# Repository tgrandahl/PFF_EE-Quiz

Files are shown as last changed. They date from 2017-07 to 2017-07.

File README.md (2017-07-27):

# PFF_EE-Quiz
EE-Quiz for PFF screening
Tyler Grandahl - July 27th 2017

The design files are provided in response to the following request:

Using KiCAD, design a circuit schematic for an analog amplifier with the following features:
-Uses a 5VDC power supply. Assumes the signal to be amplified shares the same ground as the power supply.
-Amplifies an input analog signal that can range from 0 to 2.0V so that the output ranges from 0 to 5V.
-Contains a bill of materials (BOM) specifying the chosen components and how to source them.
-Has an adjustable gain. And a low-pass filter with adjustable cut-off to filter-out noise from the input analog signal.
-OPTIONAL: Is implemented as a routed PCB.
 
The design can be submitted as a GitHub repository file containing the KiCAD project and a printable (Letter) PDF with the schematic and if available another PDF in 1:1 scale of the routed PCB.

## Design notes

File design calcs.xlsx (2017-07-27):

Amplifier Gain
rf min | 1000
rf max | 100000
ri | 10000
g min | 1.1
g max | 11
Max BW @ Max Gain
GBP | 5500000
BW @ max gain | 500000 | <= will keep max cutoff of input filter below this
Input Filter cutoff
Rin min | 1000
Rin max | 100000
Cin | 4.7e-09
fc max | 33862.75385
fc min | 338.6275385

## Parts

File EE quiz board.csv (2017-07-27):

Reference | Value | Footprint | Datasheet | MFG | MFG PN | Description
J3 | Screw_Terminal_1x02 | Connectors_Terminal_Blocks:TerminalBlock_Pheonix_MKDS1.5-2pol | https://media.digikey.com/PDF/Data%20Sheets/Phoenix%20Contact%20PDFs/1868733.pdf | Phoenix Contact | 1868733 | CONN TERM BLOCK 2POS 5.08
RV1 | 100k | Potentiometers:Potentiometer_Bourns_PTV09A-1_Horizontal | http://www.bourns.com/docs/Product-Datasheets/PTV09.pdf | Bourns | PTV09A-4025F-B104 | POT 100K OHM 1/20W CARBON LINEAR
R2 | 10k | Resistors_SMD:R_0603_HandSoldering | https://industrial.panasonic.com/cdbs/www-data/pdf/RDO0000/AOA0000C331.pdf | Panasonic Electronic Components | ERJ-PA3F1002V | RES SMD 10K OHM 1% 1/4W 0603
C3 | 0.1uF | Capacitors_SMD:C_0603_HandSoldering | http://www.kemet.com/Lists/ProductCatalog/Attachments/53/KEM_C1002_X7R_SMD.pdf | KEMET | C0603C104K4RACTU | CAP CER 0.1UF 16V X7R 0603
C2 | 4.7nF | Capacitors_SMD:C_0603_HandSoldering | http://www.kemet.com/Lists/ProductCatalog/Attachments/53/KEM_C1002_X7R_SMD.pdf | KEMET | C0603C472K4RACTU | CAP CER 4700PF 16V X7R 0603
C1 | 10uF | Capacitors_Tantalum_SMD:CP_Tantalum_Case-A_EIA-3216-18_Hand | http://www.kemet.com/Lists/ProductCatalog/Attachments/256/KEM_T2008_T494.pdf | KEMET | T494A106K016AT | CAP TANT 10UF 16V 10% 1206
U1 | OPA340D | Housings_SOIC:SOIC-8_3.9x4.9mm_Pitch1.27mm | http://www.ti.com/lit/ds/symlink/opa2340.pdf | TI | OPA340UA/2K5 | IC OP AMP GP 5.5MHZ RRIO 8SOIC
RV2 | 100k | Potentiometers:Potentiometer_Bourns_PTV09A-1_Horizontal | http://www.bourns.com/docs/Product-Datasheets/PTV09.pdf | Bourns | PTV09A-4025F-B104 | POT 100K OHM 1/20W CARBON LINEAR
J2 | Screw_Terminal_1x02 | Connectors_Terminal_Blocks:TerminalBlock_Pheonix_MKDS1.5-2pol | https://media.digikey.com/PDF/Data%20Sheets/Phoenix%20Contact%20PDFs/1868733.pdf | Phoenix Contact | 1868733 | CONN TERM BLOCK 2POS 5.08
J1 | Screw_Terminal_1x02 | Connectors_Terminal_Blocks:TerminalBlock_Pheonix_MKDS1.5-2pol | https://media.digikey.com/PDF/Data%20Sheets/Phoenix%20Contact%20PDFs/1868733.pdf | Phoenix Contact | 1868733 | CONN TERM BLOCK 2POS 5.08
D2 | D_Schottky_x2_Serial_AKC | TO_SOT_Packages_SMD:SOT-23_Handsoldering | http://www.onsemi.com/pub/Collateral/BAT54SLT1-D.PDF | ON Semiconductor | SBAT54SLT1G | DIODE ARRAY SCHOTTKY 30V SOT23-3
D1 | LED | LEDs:LED_0805_HandSoldering | https://media.digikey.com/pdf/Data%20Sheets/Lite-On%20PDFs/LTST-C171GKT.pdf | Lite-On | LTST-C171GKT | LED GREEN CLEAR 0805 SMD
R1 | 147 | Resistors_SMD:R_0603_HandSoldering | https://industrial.panasonic.com/cdbs/www-data/pdf/RDO0000/AOA0000C331.pdf | Panasonic Electronic Components | ERJ-3EKF1470V | RES SMD 147 OHM 1% 1/4W 0603

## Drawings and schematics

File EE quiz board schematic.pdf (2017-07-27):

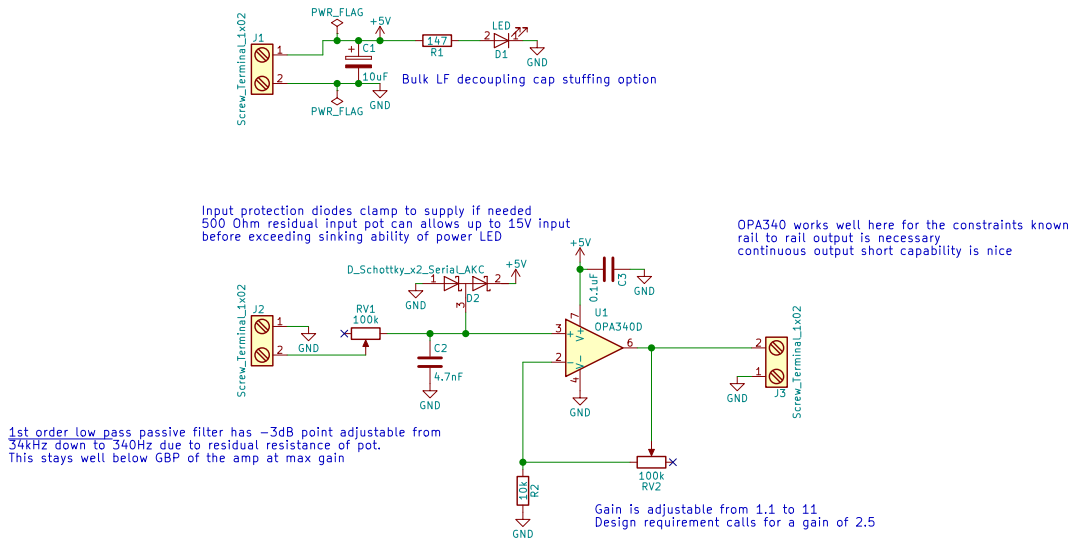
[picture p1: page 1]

Input protection diodes clamp to supply if needed
500 Ohm residual input pot can allows up to 15V input
before exceeding sinking ability of power LED

OPA340 works well here for the constraints known
rail to rail output is necessary
continuous output short capability is nice

1st order low pass passive filter has -3dB point adjustable from
34kHz down to 340Hz due to residual resistance of pot.
This stays well below GBP of the amp at max gain

Design requirement calls for a gain of 2.5 RV2
Gain is adjustable from 1.1 to 11

File: EE quiz board.sch Sheet: / Piaggio Fast Forward

Id: 1/1 Title: EE quiz board

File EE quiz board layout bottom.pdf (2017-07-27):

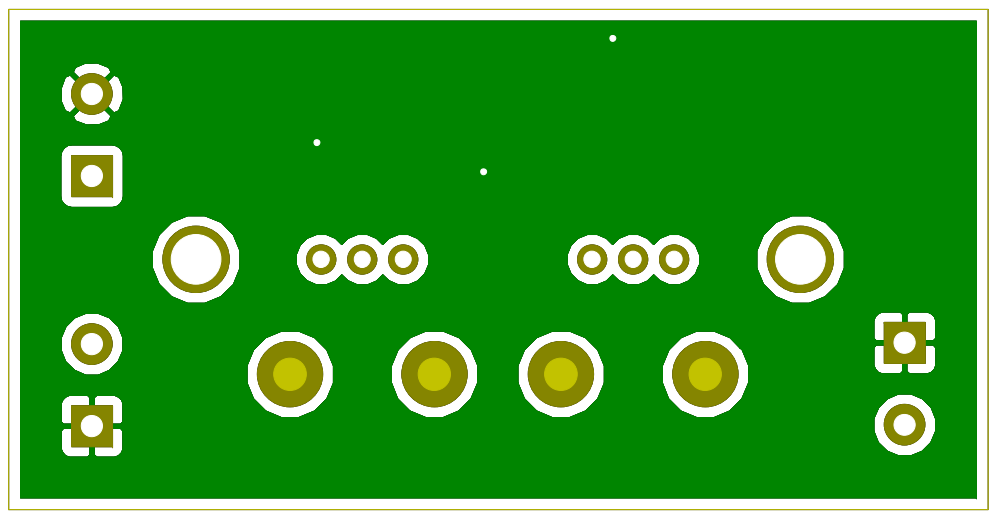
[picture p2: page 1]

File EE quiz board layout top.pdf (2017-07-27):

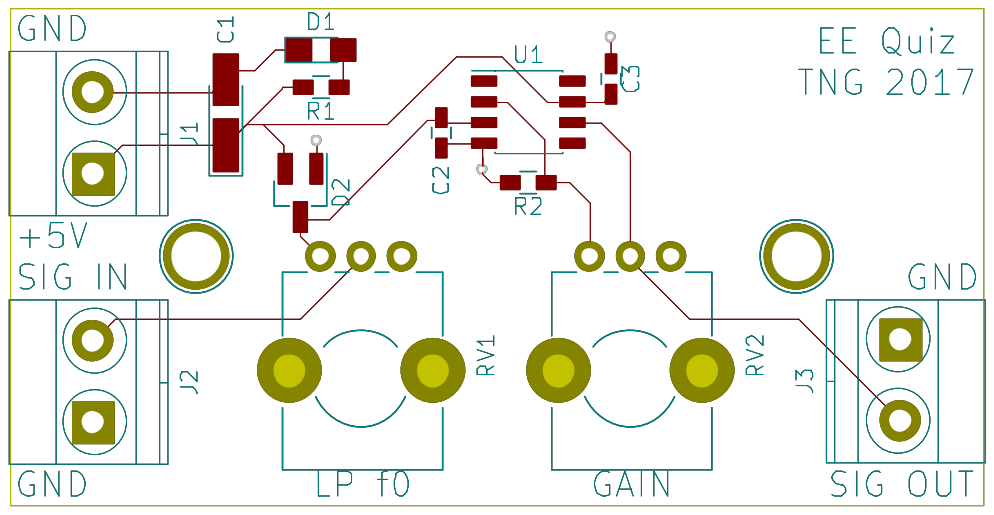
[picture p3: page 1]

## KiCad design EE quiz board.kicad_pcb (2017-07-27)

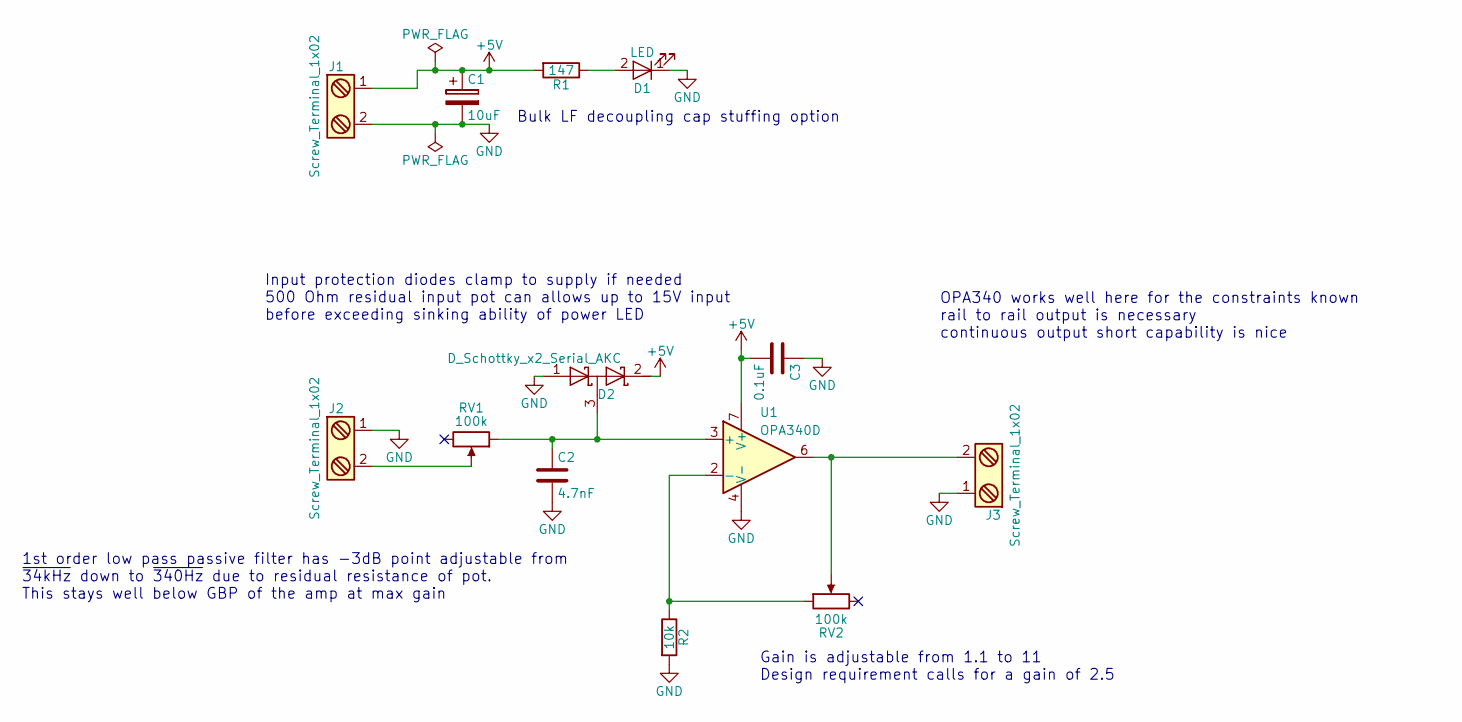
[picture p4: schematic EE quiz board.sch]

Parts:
C1: 10uF; CP_Tantalum_Case-A_EIA-3216-18_Hand; MFG PN T494A106K016AT
C2: 4.7nF; C_0603_HandSoldering; MFG PN C0603C472K4RACTU
C3: 0.1uF; C_0603_HandSoldering; MFG PN C0603C104K4RACTU
D1: LED; LED_0805_HandSoldering; MFG PN LTST-C171GKT
D2: D_Schottky_x2_Serial_AKC; SOT-23_Handsoldering; MFG PN SBAT54SLT1G
J1, J2, J3: Screw_Terminal_1x02; TerminalBlock_Pheonix_MKDS1.5-2pol; MFG PN 1868733
R1: 147; R_0603_HandSoldering; MFG PN ERJ-3EKF1470V
R2: 10k; R_0603_HandSoldering; MFG PN ERJ-PA3F1002V
RV1, RV2: 100k; Potentiometer_Bourns_PTV09A-1_Horizontal; MFG PN PTV09A-4025F-B104
U1: OPA340D; SOIC-8_3.9x4.9mm_Pitch1.27mm; MFG PN OPA340UA/2K5

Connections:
+5V: C1.1, C3.2, D2.2 (K), J1.1, R1.2, U1.7 (V+)
GND: C1.2, C2.2, C3.1, D1.1 (K), D2.1 (A), J1.2, J2.1, J3.1, R2.2, U1.4 (V-)
unnamed: C2.1, D2.3 (common), RV1.1, U1.3 (+)
unnamed: D1.2 (A), R1.1
unnamed: J2.2, RV1.2
unnamed: J3.2, RV2.2, U1.6
unnamed: R2.1, RV2.1, U1.2 (-)

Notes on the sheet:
Input protection diodes clamp to supply if needed 500 Ohm residual input pot can allows up to 15V input before exceeding sinking ability of power LED
OPA340 works well here for the constraints known rail to rail output is necessary continuous output short capability is nice
1st order low pass passive filter has -3dB point adjustable from ~34kHz down to ~340Hz due to residual resistance of pot. This stays well below GBP of the amp at max gain
Gain is adjustable from 1.1 to 11 Design requirement calls for a gain of 2.5
Bulk LF decoupling cap stuffing option

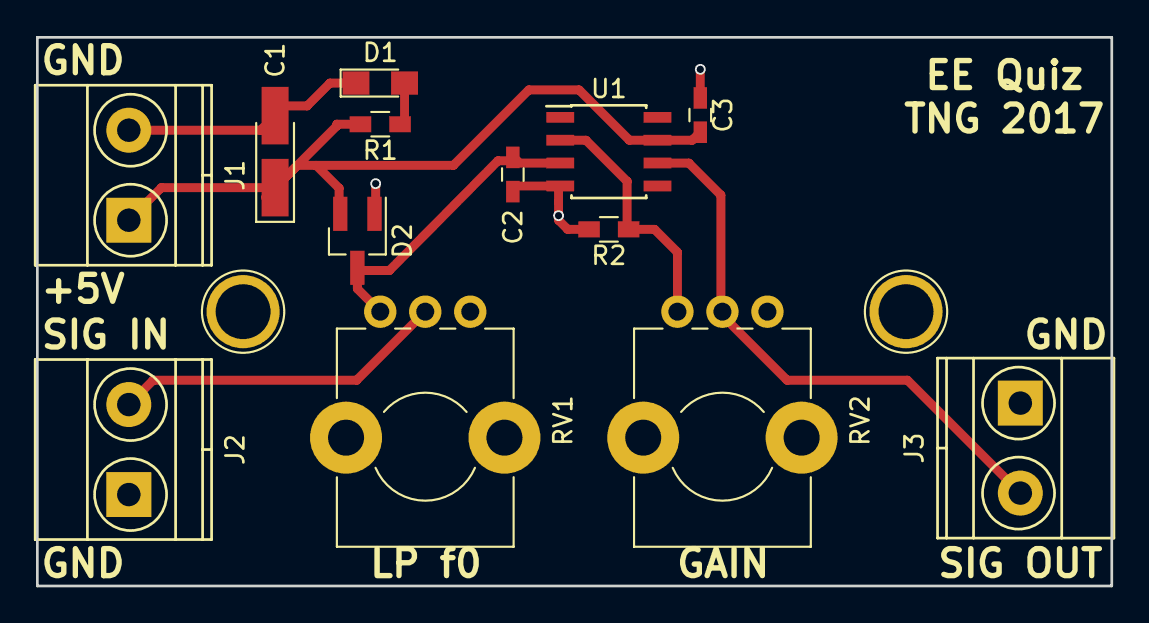
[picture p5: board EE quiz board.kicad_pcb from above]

Board: 2 copper layers, 59.7 x 30.5 mm, 13 parts (0 on the bottom side), 7 nets.
